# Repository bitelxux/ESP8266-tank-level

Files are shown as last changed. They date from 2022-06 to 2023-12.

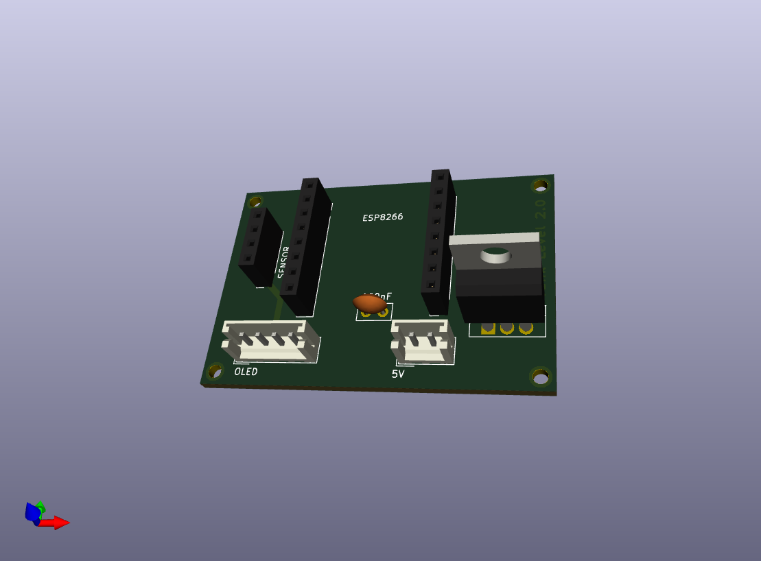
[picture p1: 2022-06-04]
kicad/water.tank/board.png

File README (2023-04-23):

2023/04/22
===================================================================================

Created branch DHT-11

2023/04/21
===================================================================================

Last kown working environment

Arduino IDE 2.1.0

Libaries:

Name                    Installed Available Location              Description                           
Adafruit_BusIO          1.14.1    -         LIBRARY_LOCATION_USER -                                     
Adafruit_GFX_Library    1.11.5    -         LIBRARY_LOCATION_USER -                                     
Adafruit_SSD1306        2.5.7     -         LIBRARY_LOCATION_USER -                                     
Adafruit_Unified_Sensor 1.1.9     -         LIBRARY_LOCATION_USER -                                     
ArduinoJson             5.13.5    6.21.2    LIBRARY_LOCATION_USER An efficient and elegant JSON library...
cnn                               -         LIBRARY_LOCATION_USER -                                     
DHT_sensor_library      1.4.4     -         LIBRARY_LOCATION_USER -                                     
ESP_DoubleResetDetector 1.3.2     -         LIBRARY_LOCATION_USER -                                     
NTPClient               3.2.1     -         LIBRARY_LOCATION_USER -                                     
WiFiManager             2.0.15-rc.1 -       LIBRARY_LOCATION_USER - 

Board: Generic ESP8266 board (3.0.2)

2022/05/13
===================================================================================

New version of https://github.com/bitelxux/levelsensor

Based in a ESP8266 reading from the sensor and uploading to a server
where very likely Grafana will show a nice chart.

It supports connection outages by storing values locally with a timestamp
and sending them once the connection is resumed.

This version will have a lot of improvements like pseudo-threads, 
smart use of EEPROM to store readings when connection to the server is not available,
WiFiManager to dynamically manage connections from any browser,
commands inyection from the server to force actions to happen in the
ESP like EEPROM reset or forget WiFis and much more !!

It's a Work in Progress !! Far from being finished !

Also the servers (tank level server and logs server) are not finished.

Link 'cnn' library to arduino's libraries directory
That 'cnn' library will be split from the main code at some point.
And it needs a proper name !

Keep syntonized if you want to see where this ends

First environment
============================================

 - Arduino IDE 1.8.15
 - Arduino AVR board 1.8.3
 - ESP8266 2.7.0

https://arduino.esp8266.com/stable/package_esp8266com_index.json
board: NodeMCU1.0 (ESP-12E Module)

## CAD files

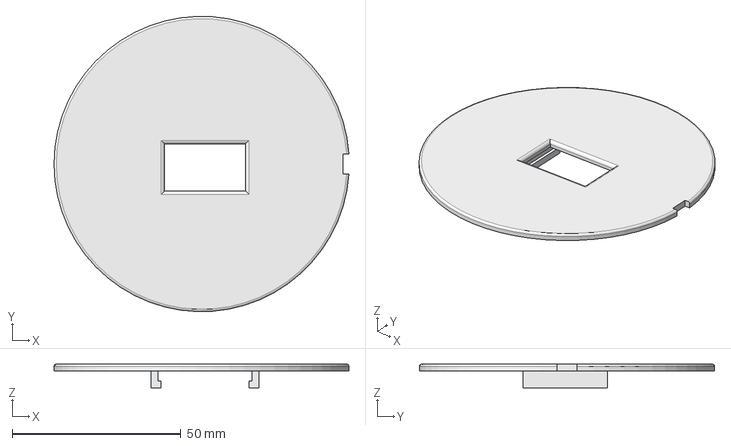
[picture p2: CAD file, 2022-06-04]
freecad/enclosure.FCStd
87.5 x 87.5 x 7.10 mm

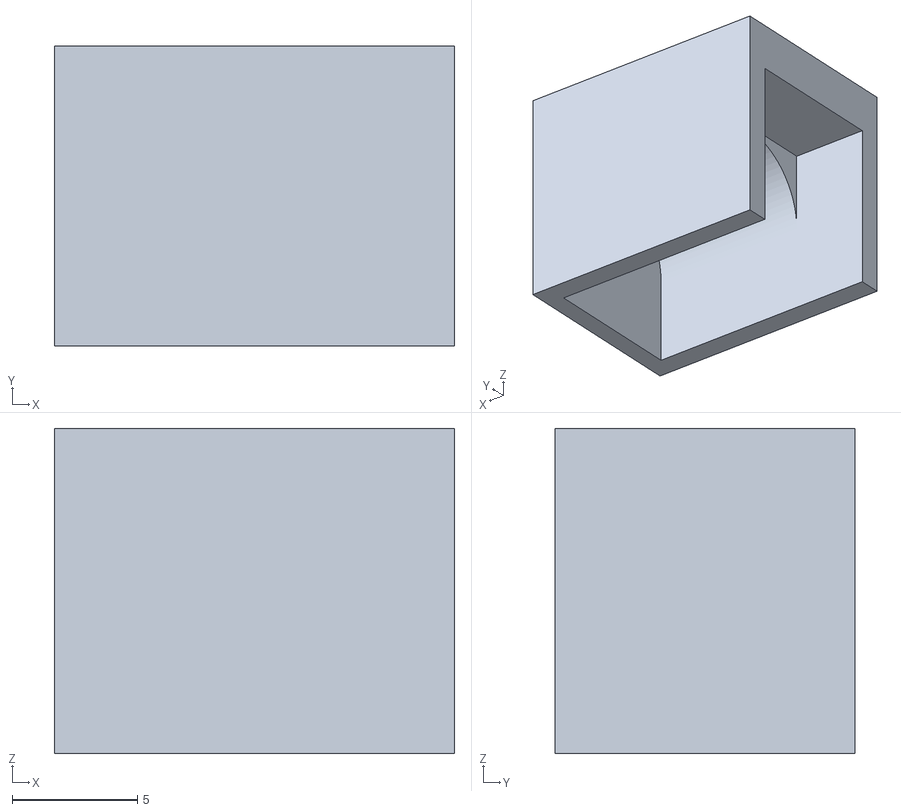
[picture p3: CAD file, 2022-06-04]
freecad/conector.stl
16.0 x 12.0 x 13.0

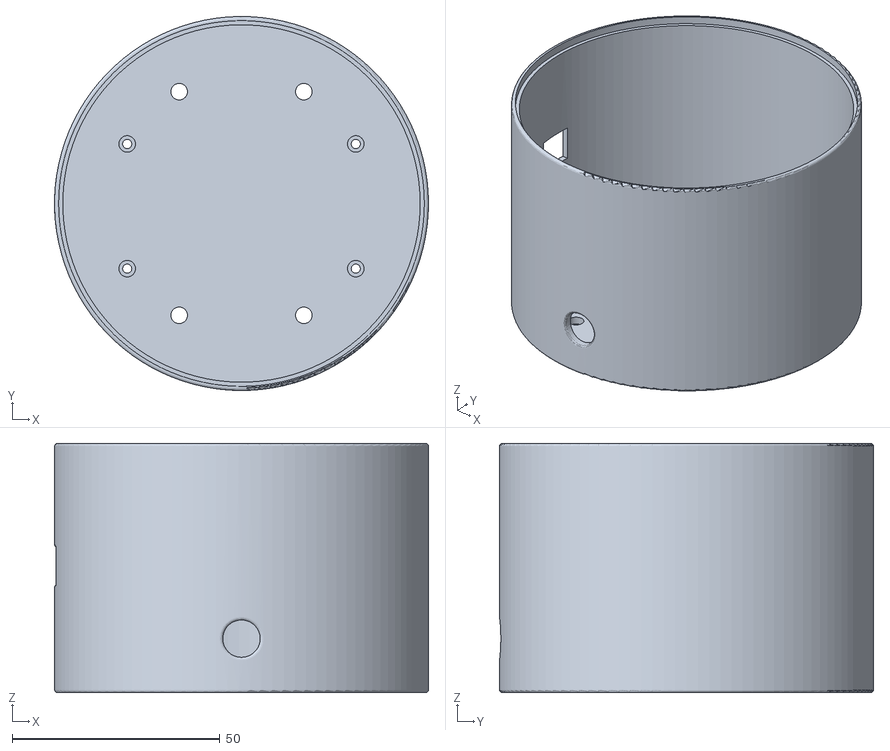
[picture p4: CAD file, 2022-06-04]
freecad/caja.stl
90.0 x 90.0 x 60.0

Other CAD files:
freecad/tapa.stl

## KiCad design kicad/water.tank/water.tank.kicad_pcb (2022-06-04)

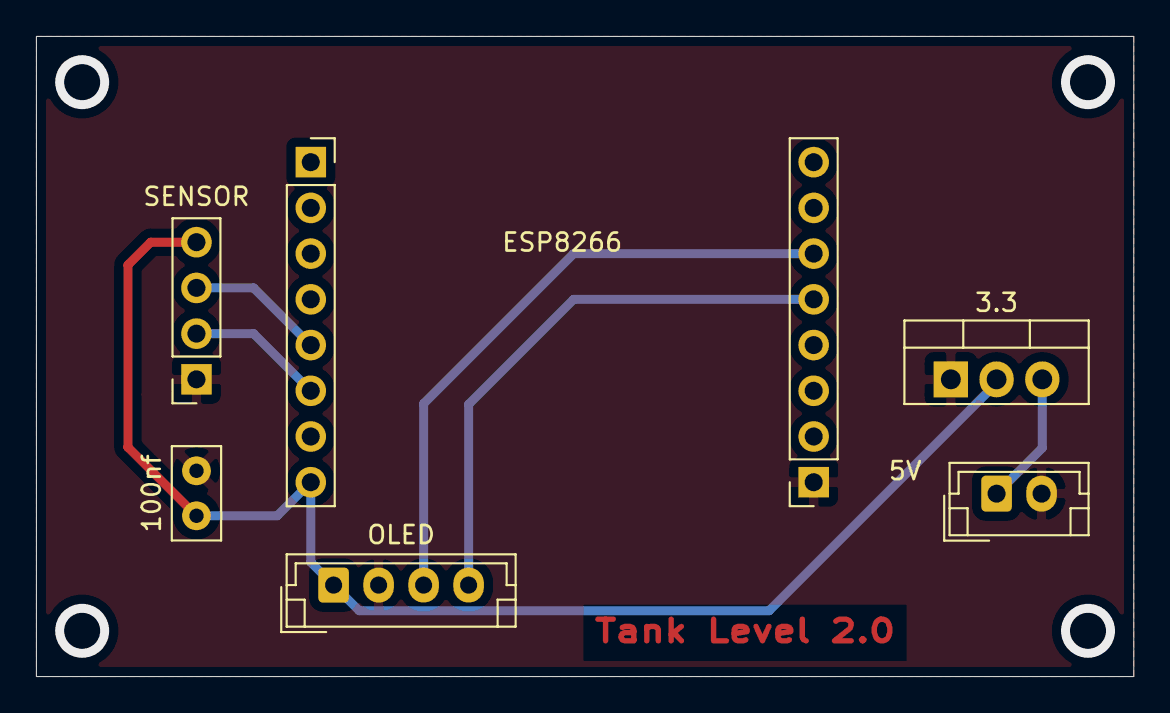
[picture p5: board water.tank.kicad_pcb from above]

Board: 2 copper layers, 61.0 x 35.6 mm, 7 parts (0 on the bottom side), 7 nets.

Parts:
3.3: LD33V; TO-220-3_Vertical
5V: source; JST_EH_B2B-EH-A_1x02_P2.50mm_Vertical
100nf: CAP; C_Disc_D5.0mm_W2.5mm_P2.50mm
ESP8266: ESP8266; PinSocket_1x08_P2.54mm_Vertical
J1: ESP8266; PinSocket_1x08_P2.54mm_Vertical
OLED: OLED1; JST_EH_B4B-EH-A_1x04_P2.50mm_Vertical
SENSOR: r; PinSocket_1x04_P2.54mm_Vertical

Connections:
5V: 3.3.3, 5V.1
GND: 3.3.1, 5V.2, 100nf.2, ESP8266.1, OLED.2, SENSOR.1
IO04: ESP8266.5, OLED.4
IO05: ESP8266.6, OLED.3
IO12: J1.6, SENSOR.2
IO14: J1.5, SENSOR.3
VCC: 3.3.2, 100nf.1, J1.8, OLED.1, SENSOR.4

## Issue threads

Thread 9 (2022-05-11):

make a first read after boot

bitelxux, 2022-05-11:
Or change the timers to be fired at t0
The problem as the read and display are not updated until the first read that now happens at t0+timer

bitelxux, 2022-05-13:
done

Closed 2022-05-13.

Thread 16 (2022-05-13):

test new JSN-SR20-Y1 double sensor

bitelxux, 2022-05-13:
configure it to continuosly send reading over serial. 47K resistor.

bitelxux, 2022-05-13:
I didn't have any smd 47K resistor. Soldered a regular one making the JSN-SR20-Y1 to look like if it has grown some weird organ

bitelxux, 2022-05-13:
done

Closed 2022-05-13.

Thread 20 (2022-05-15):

support jsn sensor mode 1 too

bitelxux, 2022-05-15:
Initial testing was done with sensor on mode 2, after soldering a 47K resistor, it continuosly sends the distance over serial.
But I have managed to ruin the solder area for the resistor and I can't solder it again so I need to support mode 1 now ( trigger + echo ) as I don't have another JSN board at the moment.

Closed 2022-05-15.

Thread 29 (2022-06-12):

Implement reset  button

bitelxux, 2022-06-12:
To be pressed for let's  say 10 seconds and then  reset WiFi configuration and EEPROM

bitelxux, 2022-06-12:
Implemented on GPIO14
If it's connected to ground for longer than 10 seconds, the wifi configuration will  be reseted and EEPTOM deleted.
Board will reboot too and Wifi will need to be re-configured

Closed 2022-06-12.

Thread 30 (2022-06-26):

Add REST server

bitelxux, 2022-06-26:
ref: https://www.mischianti.org/2020/05/16/how-to-create-a-rest-server-on-esp8266-and-esp32-startup-part-1/

For:

- reset EEPROM
- get stats
- force reading
- etc

Closed 2022-07-22.

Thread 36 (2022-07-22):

Use NTP + millis()

bitelxux, 2022-07-22:
Allow the recording of readings when there is no connection to the server if, at least, time was synced at some point

bitelxux, 2022-07-23:
Doesn't work. Reverting change.

Closed 2022-07-24.

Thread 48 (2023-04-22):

New arduino IDE (2.1.0) ATM

bitelxux, 2023-04-22:
```
Arduino IDE 2.1.0

Libaries:

Name                    Installed Available Location              Description                   
Adafruit_BusIO          1.14.1    -         LIBRARY_LOCATION_USER -                             
Adafruit_GFX_Library    1.11.5    -         LIBRARY_LOCATION_USER -                             
Adafruit_SSD1306        2.5.7     -         LIBRARY_LOCATION_USER -                             
Adafruit_Unified_Sensor 1.1.9     -         LIBRARY_LOCATION_USER -                             
ArduinoJson             5.13.5    6.21.2    LIBRARY_LOCATION_USER An efficient and elegant JSON library...
cnn                               -         LIBRARY_LOCATION_USER -                             
DHT_sensor_library      1.4.4     -         LIBRARY_LOCATION_USER -                             
ESP_DoubleResetDetector 1.3.2     -         LIBRARY_LOCATION_USER -                             
NTPClient               3.2.1     -         LIBRARY_LOCATION_USER -                             
WiFiManager             2.0.15-rc.1 -       LIBRARY_LOCATION_USER -

Board: Generic ESP8266 board (3.0.2)

```

bitelxux, 2023-04-22:
Program building and working.

Closed 2023-04-22.

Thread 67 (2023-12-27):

Prevent wifimanager to start WebPortal when configured ESSID is not available

bitelxux, 2023-12-27:
If the board starts and there is a configured SSID but it's not available, it will start the WebPortal to configure WIFI and hang there.

Prevent the WebPortal from starting IF a SSID is configured. Rather than that, wait for the SSID to become available.

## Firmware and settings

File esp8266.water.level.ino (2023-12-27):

//Libraries
#include <FS.h>
#include <ArduinoJson.h>     // 5.13.5 !!

#include <ESP8266WebServer.h>

#include <cnn.h>
#include "sensor_JSN-SR04T.h"

// This is for each variable to use it's real size when stored
// in the EEPROM
#pragma pack(push, 1)

#define BOARD_ID "tank.Z"
#define VERSION "20231227.272"

//EEPROM
#define EEPROM_SIZE 4096
#define RESERVED_BYTES 10
#define COUNTER_SLOTS 10

#define CURRENT_COUNTER_SLOT_ADDRESS 0   // 1 byte
#define MAX_WRITES 100000                // theorically 10000
#define WARNINGS_ADDRESS 1               // bitmap supporting 8 predefined warnings
#define BOOTS_ADDRESS 2                  // 2 bytes

#define WARNING_COUNTER_SLOTS_ROTATED  1 // counter slots were exhaested and ressetted to 1
#define WARNING_STORAGE_IS_FULL 2
#define WARNING_2 4
#define WARNING_3 8
#define WARNING_4 16
#define WARNING_5 32
#define WARNING_6 64
#define WARNING_7 128

#define FLUSH_BATCH_SIZE 50

#define REC_NEVER_USED 0
#define REC_IN_USE 1
#define REC_FLUSHED 2

// 10 bytes are reserver for general data
// we reserve space for 10 counters, 4 byte each
// for each counter, first two bytes is the number
// of write operations on the counter
// the second two bytes is the counter itself
// #define RECORDS_BASE_ADDRESS RESERVED_BYTES + 4 * COUNTER_SLOTS 
//\\ EEPROM

#define RSSI_MAX -50  // maximum strength of signal in dBm
#define RSSI_MIN -100 // minimum strength of signal in dBm

// WiFiManager parameteres
#define SERVER_LABEL "SERVER_IP"

// Reset Button
#define RESET_BUTTON 14
unsigned long rb_last_change = 0;
int rb_required_time = 3;
boolean time_to_reset = false;

App *app = NULL;
SR04T_sensor* sensor = NULL;

//flag for saving data
bool shouldSaveConfig = false;

//callback notifying us of the need to save config
void saveConfigCallback () {
  Serial.println("Should save config");
  shouldSaveConfig = true;
}

typedef struct
{
  byte flag;
  unsigned long timestamp;
  unsigned short value;
} Reading;

unsigned short int RECORDS_BASE_ADDRESS = RESERVED_BYTES + 4 * COUNTER_SLOTS;
unsigned short int MAX_RECORDS = (EEPROM_SIZE - RECORDS_BASE_ADDRESS)/sizeof(Reading) -1;
// TODO review that -1. It's not the best approach

int counter = 0; // number of registers in EEPROM
int lastReading = 0;
char buffer[200];

// prototipes
void flushStoredData();
void registerNewReading();

ESP8266WebServer restServer(80);

// This values  will depend on what the user configures
// on the  WifiManager on the first connection
char server[16];
char log_server[30];
char baseURL[30];

//OLED
#include <SPI.h>
#include <Wire.h>
#include <Adafruit_GFX.h>
#include <Adafruit_SSD1306.h>

boolean displayInitialized = false;

#define SCREEN_WIDTH 128 // OLED display width, in pixels
#define SCREEN_HEIGHT 64 // OLED display height, in pixels

// Declaration for an SSD1306 display connected to I2C (SDA, SCL pins)
#define OLED_RESET     -1 // Reset pin # (or -1 if sharing Arduino reset pin)

// SCL is GPI05
// SDA is GPI04
Adafruit_SSD1306 display(SCREEN_WIDTH, SCREEN_HEIGHT, &Wire, OLED_RESET);

static const unsigned char PROGMEM wifi_bmp[] = 
{
0x00, 0x00, 0x00, 0x00, 0x07, 0xe0, 0x1f, 0xf8, 0x70, 0x0e, 0xe0, 0x07, 0x07, 0xe0, 0x1e, 0x78,
0x18, 0x18, 0x03, 0xc0, 0x07, 0xe0, 0x00, 0x00, 0x01, 0x80, 0x01, 0x80, 0x00, 0x00, 0x00, 0x00
};

static const unsigned char PROGMEM nowifi_bmp[] = 
{
0x00, 0x01, 0x00, 0x3e, 0x01, 0xfe, 0x00, 0xfe, 0x00, 0xfe, 0x01, 0xfe, 0x03, 0x3c, 0x20, 0x3c,
0x30, 0x64, 0x38, 0x40, 0x7c, 0x00, 0x7e, 0x00, 0x7f, 0x00, 0x7f, 0x80, 0x7c, 0x00, 0x80, 0x00
};

static const unsigned char PROGMEM send_bmp[] = 
{
0x00, 0x00, 0x09, 0x00, 0x04, 0x00, 0x00, 0x80, 0x02, 0x40, 0x01, 0x20, 0x00, 0x80, 0x00, 0x90,
0x00, 0x90, 0x00, 0x80, 0x01, 0x20, 0x02, 0x40, 0x00, 0x80, 0x04, 0x00, 0x09, 0x00, 0x00, 0x00
};

static const unsigned char PROGMEM store_bmp[] = 
{
0x7f, 0xfc, 0xe0, 0x6e, 0xe0, 0x6f, 0xe0, 0x6f, 0xe0, 0x6f, 0xe0, 0x2f, 0xff, 0xff, 0xff, 0xff,
0xc0, 0x03, 0xc0, 0x03, 0xc0, 0x03, 0xc0, 0x03, 0xc0, 0x03, 0xc0, 0x03, 0xc0, 0x03, 0x7f, 0xfe
};

static const unsigned char PROGMEM disconnected_bmp[] = 
{
0x00, 0x01, 0x00, 0x3e, 0x01, 0xfe, 0x00, 0xfe, 0x00, 0xfe, 0x01, 0xfe, 0x03, 0x3c, 0x20, 0x3c,
0x30, 0x64, 0x38, 0x40, 0x7c, 0x00, 0x7e, 0x00, 0x7f, 0x00, 0x7f, 0x80, 0x7c, 0x00, 0x80, 0x00
};

static const unsigned char PROGMEM connected_bmp[] = 
{
0x00, 0x01, 0x00, 0x02, 0x00, 0x64, 0x00, 0xf8, 0x07, 0xf8, 0x0b, 0xfc, 0x0d, 0xfc, 0x1e, 0xf8,
0x1f, 0x78, 0x3f, 0xb0, 0x3f, 0xd0, 0x1f, 0xe0, 0x1f, 0x00, 0x26, 0x00, 0x40, 0x00, 0x80, 0x00
};

static const unsigned char PROGMEM warning_bmp[] = {
	0x00, 0x00, 0x00, 0x00, 0x00, 0x00, 0x01, 0x80, 0x01, 0x80, 0x02, 0x40, 0x06, 0x60, 0x06, 0x60, 
	0x0e, 0x70, 0x1f, 0xf8, 0x1e, 0x78, 0x3e, 0x7c, 0x00, 0x00, 0x00, 0x00, 0x00, 0x00, 0x00, 0x00
};

void clearSection(int x, int y, int x1, int y1){
  display.fillRect(x, y, x1, y1, 0);
  display.display();
}

void drawTank(){
  sensor->draw(&display, lastReading);
}

void drawStore(){
  display.drawBitmap(94, 0, store_bmp, 16, 16, 1);
  display.display();
}

void drawSend(){
  display.drawBitmap(94, 0, send_bmp, 16, 16, 1);
  display.display();
}

void updateDisplay(){

  if (!displayInitialized) {
    Serial.println("Display not initialized");
    return;
  }

  display.clearDisplay();

  drawTank();

  if (readWarnings()){
      display.drawBitmap(18, 0, warning_bmp, 16, 16, 1);
  }

  if (isServerAlive()){
      display.drawBitmap(0, 0, connected_bmp, 16, 16, 1);
  }
  else
  {
      display.drawBitmap(0, 0, disconnected_bmp, 16, 16, 1);
  }

  if (WiFi.status() == WL_CONNECTED){
      display.drawBitmap(112, 0, wifi_bmp, 16, 16, 1);
  }
  else
  {
      display.drawBitmap(112, 0, nowifi_bmp, 16, 16, 1);
  }

  display.setTextSize(1);             // Normal 1:1 pixel scale
  display.setTextColor(WHITE);        // Draw white text
  display.setCursor(0,18);            

  display.setCursor(40,5);            
  display.print(BOARD_ID);

  display.setCursor(0,18);
  display.print(sensor->READ_LABEL);
  display.setCursor(46,18);            
  display.print(lastReading);

  unsigned short int counter = readCounter();
  display.setCursor(0,26);            
  display.print("Local: ");
  display.setCursor(46,26);            
  display.print(counter);

  display.setCursor(0,48);            
  display.print(VERSION);

  display.setCursor(0,56);            
  display.print(app->IP);

  display.display();
}

void initOLED(){

  // SSD1306_SWITCHCAPVCC = generate display voltage from 3.3V internally
  if(display.begin(SSD1306_SWITCHCAPVCC, 0x3C)) { 
    Serial.println("SSD1306 found and intialized");
    displayInitialized = true;
  }
  else {
    Serial.println("SSD1306 allocation failed");
  }

  // Show initial display buffer contents on the screen --
  // the library initializes this with an Adafruit splash screen.
  display.display();
  delay(2000); // Pause for 2 seconds
}

bool isServerAlive(){
    sprintf(buffer, "%s/ping", baseURL);
    //Serial.println(buffer);
    return (app->send(buffer));
}

void registerNewReading(){
  int distance;
  int counter;
  char buffer[100];

  // some attempts to read a value from sensor
  for (int i=0; i<10; i++){
      distance = sensor->read();
      if (distance != -1){
        break;
      }
      delay(20);
  }

  if (distance <= 0){
    app->log("Error reading value from sensor");
    return;
  }

  sprintf(buffer, "LOG: read distance is %d", distance);
  app->log(buffer);

  int litres = sensor->calcLitres(distance);
  lastReading = litres;

  unsigned long now = app->getEpochSeconds();
  if (now){
    sprintf(buffer, "%s/add/%d:%d", baseURL, now, litres);

    // try to send to the server
    // if fails, store locally for further retrying
    if (app->send(buffer)){
      drawSend();
      sprintf(buffer, "Sent %d:%d", now, litres);
      app->log(buffer);
    }
    else{
      drawStore();
      counter = writeReading(now, litres);
    }
        
  }
  else{
      app->log("Warning: Not handling reading as time is not synced");
  }

}

void flushStoredData(){


  Reading reading;  
  unsigned short int counter = readCounter();
  unsigned short int cursor = 0;
  unsigned short int regAddress;
  short int value;
  bool errors = false;
  byte flag;
  unsigned short int recNum;
  unsigned short int sent = 0;
  int regSize = sizeof(reading);
  char buffer[100];
 
  // You have to start server.py at BASE_URL
  if (!isServerAlive()){
    sprintf(buffer, "[FLUSH_STORED_DATA] Server doesn't respond. I'll try later.");
    app->log(buffer);
    return;
  }

  if (WiFi.status() != WL_CONNECTED){
    app->log("[FLUSH_STORED_DATA] Skipping. I'm not connected to the WIFI :-/.");
    return;
  }

  if (counter == 0){
      app->log("[FLUSH_STORED_DATA] Nothing to send");
      return;
  }

  for (regAddress = RECORDS_BASE_ADDRESS; regAddress < EEPROM_SIZE; regAddress += regSize){

      if (counter == 0 || sent >= FLUSH_BATCH_SIZE){
         break;
      }
      
      EEPROM.get(regAddress, reading);

      // if value is REC_FLUSHED that register was already sent
      // 0 the position hasn't been used yet
      if (reading.flag == REC_FLUSHED){
        continue;
      }

      // flag 0 means that position or higher have never been used
      if (reading.flag == REC_NEVER_USED){
        return;
      }

      recNum = (regAddress - RECORDS_BASE_ADDRESS)/regSize;
      sprintf(buffer, "%s/add/%d:%d", baseURL, reading.timestamp, reading.value);

      if (!app->send(buffer)){
        sprintf(buffer, "[FLUSH_STORED_DATA] Error sending record [%d]", recNum);
        app->log(buffer);
        errors = true;
        if (!isServerAlive()){
          sprintf(buffer, "[FLUSH_STORED_DATA] Server doesn't respond. I'll try later.");
          app->log(buffer);
          break;
        }

      }
      else
      {
        drawSend();
        counter = decCounter();
        sent ++;
        
        sprintf(buffer, "[FLUSH_STORED_DATA] Success sending record [%d] (%d left)", recNum, readCounter());
        app->log(buffer);

        // We don't want to write the whole struct to save write cycles
        flag = REC_FLUSHED;
        EEPROM.write(regAddress, flag);
        EEPROM.commit();

        removeWarning(WARNING_STORAGE_IS_FULL);

        updateDisplay();
      }

  }

  if (!errors){
      sprintf(buffer, "[FLUSH_STORED_DATA] %d records sent", sent);
      // to correct a buggy counter out of sync error that sometimes happens
      if (sent == 0){
        writeCounter(0);
      }
  } else {
      sprintf(buffer, "[FLUSH_STORED_DATA] %d records sent [errors]", sent);    
  }
  
  app->log(buffer);

}

unsigned short int incCounter(){
  counter = readCounter() + 1;
  writeCounter(counter);
  return counter;
}

unsigned short int decCounter(){
  counter = readCounter() - 1;
  writeCounter(counter);
  return counter;
}

byte readWarnings(){
  byte warnings;   
  warnings = EEPROM.read(WARNINGS_ADDRESS);
  return warnings;
}

void removeWarnings(){
  EEPROM.write(WARNINGS_ADDRESS, 0);
  EEPROM.commit();
}

byte removeWarning(byte warning){
  byte warnings = readWarnings();
  if (!(warnings && warning)){
    // warning was not set. nothing to remove
    return warnings;
  }
  warnings ^= warning;
  EEPROM.write(WARNINGS_ADDRESS, warnings);
  EEPROM.commit();
  return warnings;
}

byte addWarning(byte warning){
  byte warnings = readWarnings();
  warnings |= warning;
  EEPROM.write(WARNINGS_ADDRESS, warnings);
  EEPROM.commit();
  return warnings;
}

unsigned short int readCounter(){
  byte counterAddress;   
  unsigned short int counter;
  EEPROM.get(CURRENT_COUNTER_SLOT_ADDRESS, counterAddress);
  EEPROM.get(counterAddress + 2, counter); // skip counter writes: 2 bytes
  return counter;
}

int getCounterSlot(){
  byte counterAddress;
  int counterSlot;

  EEPROM.get(CURRENT_COUNTER_SLOT_ADDRESS, counterAddress);
  counterSlot = (counterAddress-RESERVED_BYTES-1)/4 + 1;
  return counterSlot;
}

void writeCounter(unsigned short int counter){
  byte counterAddress;
  int counterSlot;
  unsigned short int counterWrites;

  EEPROM.get(CURRENT_COUNTER_SLOT_ADDRESS, counterAddress);
  EEPROM.get(counterAddress, counterWrites);

  counterSlot = getCounterSlot();

  if (counterWrites >= MAX_WRITES){
    // We are about to reach the 10K writes limit ...
    // moving to the next slot

    //sprintf(buffer, "Counter slot %d reaching the limit of %d writings", counterSlot, MAX_WRITES);
    //app->log(buffer);

    if (counterSlot <  COUNTER_SLOTS){
        counterSlot ++;
        counterAddress += 4; // each counter is 2 byte for n of writes + 2 bytes for the counter
        sprintf(buffer, "Counter slot moved to slot %d", counterSlot);
        app->log(buffer);
    }
    else{
        sprintf(buffer, "WARNING. Counter slots exhausted. Resetting to slot 1. Writes might start to fail soon");
        addWarning(WARNING_COUNTER_SLOTS_ROTATED);
        app->log(buffer);
        counterSlot = 1;
        counterAddress = 1;
    }

    counterWrites = 0;

    EEPROM.write(CURRENT_COUNTER_SLOT_ADDRESS, counterAddress);
  }

  EEPROM.put(counterAddress, counterWrites+1);
  EEPROM.put(counterAddress + 2, counter);
  
  //sprintf(buffer, "counter slot: %d, numwrites: %d", counterSlot, counterWrites+1);
  //app->log(buffer);

  if (!EEPROM.commit()) {
    app->log("Commit failed writing counter changes");
  }
}

int writeReading(unsigned long in_timestamp, short int in_value){
  
  int address;
  int regAddress;
  unsigned short int counter = readCounter();
 
  //sprintf(buffer, "writeReading %d %d", counter, MAX_RECORDS);
  //app->log(buffer);

  if (counter >= MAX_RECORDS){
    addWarning(WARNING_STORAGE_IS_FULL);
    app->log("WARNING. Local storage is full");
    return -1;
  }

  Reading newReading;
  Reading record;
  Reading currentReading;
  
  newReading.timestamp = in_timestamp;
  newReading.value = in_value;
  newReading.flag = REC_IN_USE;

  int regSize = sizeof(newReading);
  byte flag;

  for (address=RECORDS_BASE_ADDRESS; address < EEPROM_SIZE - regSize; address += regSize){
      EEPROM.get(address, flag);
      // flag is a used position
      if (flag != REC_IN_USE){
        EEPROM.put(address, newReading);
        EEPROM.commit();
        counter = incCounter();        
        sprintf(buffer, "Locally stored [%d of %d] %d:%d", counter, MAX_RECORDS, in_timestamp, in_value);
        app->log(buffer);
        break;
      }      
  }  

  return counter;
}

void dumpEEPROM(){

  unsigned short _byte;
  int offset = 0;
  int n = -1;
  boolean usingDefault = true;

  int freeRAM = ESP.getFreeHeap();

  sprintf(buffer, "free RAM = %d", freeRAM);
  app->log(buffer);
  
  if ( restServer.hasArg("n") ) {
    n = restServer.arg("n").toInt();
    usingDefault = false;
  }
  else {
    n = 10;
  }

  if ( n*12 > freeRAM) {
     restServer.send(200, "text/plain", "Not enough free RAM. Try to request less positions\n");
     return;
  }

  char buffer[n*12];

  if ( usingDefault ){
    sprintf(buffer, "'n' hasn't been specified. Defaulting to 10\n\n");
    offset=strlen(buffer);
    n = 10;
  }

  for (int i = 0; i < n; i++) {
    _byte = EEPROM.read(i);
    offset += sprintf(buffer + offset, "0x%04X: %d\n",i ,_byte);
  }

  restServer.send(200, "text/plain", buffer);
}

void resetEEPROM(){
  int t0 = millis();
  for (int i=0; i < EEPROM_SIZE; i++){
    EEPROM.write(i, 0);
  }

  EEPROM.write(CURRENT_COUNTER_SLOT_ADDRESS, RESERVED_BYTES);

  EEPROM.commit();
  int t2=millis();

  sprintf(buffer, "EEPROM deleted in %d milliseconds", t2 - t0);
  app->log(buffer);

  restServer.send(200, "text/plain", buffer);
}

void resetWIFI(){

  sprintf(buffer, "WIFI networks will be reset and board rebooted NOW");
  app->log(buffer);
  restServer.send(200, "text/plain", buffer);
  _resetWifi();
}

void readConfigFile(){
  Serial.println("mounting FS...");
  strcpy(server, "");

  if (SPIFFS.begin()) {
    Serial.println("mounted file system");
    if (SPIFFS.exists("/config.json")) {
      //file exists, reading and loading
      Serial.println("reading config file");
      File configFile = SPIFFS.open("/config.json", "r");
      if (configFile) {
        Serial.println("opened config file");
        size_t size = configFile.size();
        // Allocate a buffer to store contents of the file.
        std::unique_ptr<char[]> buf(new char[size]);

        configFile.readBytes(buf.get(), size);
        DynamicJsonBuffer jsonBuffer;
        JsonObject& json = jsonBuffer.parseObject(buf.get());
        json.printTo(Serial);
        if (json.success()) {
          Serial.println("\nparsed json");
          strcpy(server, json["server"]);
        } else {
          Serial.println("failed to load json config");
        }
      }
    }
  } else {
    Serial.println("failed to mount FS");
  }
}

ICACHE_RAM_ATTR void resetButtonPushed() {

    char buffer[20];
    static int t0 = millis();
    static bool armed = false;
    
    if (millis() - t0 < 200){
       t0 = millis();
       return;
    }

    if (!armed && digitalRead(RESET_BUTTON) == 0){ // pressed
       t0 = millis();
       armed = true;
    }

    if (armed && millis() - t0 > 10000){
       armed = false;
       time_to_reset = true;
       return;
    }
    
    if (digitalRead(RESET_BUTTON) == 1){ //released too soon
       Serial.println("RESET not performed");      
       armed = false;
    }

}

void checkConnection()  {
    if (WiFi.status() != WL_CONNECTED) {
      Serial.println("Reconnecting to WiFi...");
      WiFi.reconnect();
      
      int t = millis();
      
      while (millis() - t < 60000 && WiFi.status() != WL_CONNECTED){
        delay(2000);
        Serial.println("Reconnecting to WiFi...");
      }

      if (WiFi.status() == WL_CONNECTED){
        Serial.println("WiFi reconnected!");
      }
      else {
        Serial.println("Failed to reconnect to WiFi");
      }

    }
}

void isTimeToReset(){
  if (time_to_reset){
    app->log("RESET button has been pressed for more than 10 seconds. Resetting WIFI and  EEPROM");
    resetEEPROM();
    _resetWifi();
  }
}

char* millis_to_human(unsigned long millis)
{
    char* buffer = new char[100];

    int seconds = millis/1000;

    int days = int(seconds/86400);
    seconds = seconds % 86400;
    int hours = int(seconds/3600);
    seconds = seconds % 3600;
    int minutes = int(seconds/60);
    seconds = seconds % 60;

    sprintf(buffer, "%d days, %d hours, %d minutes, %d seconds", days, hours, minutes, seconds);
    return buffer;
}

// Serving Hello world
void getHelloWord() {
    restServer.send(200, "text/json", "{\"name\": \"Hello world\"}");
}

void boardID() {
    sprintf(buffer, "%s\n", BOARD_ID);
    restServer.send(200, "text/plain", buffer);
}

void scan_networks() {

  char *buffer = new char[1024];
  int n = WiFi.scanNetworks();
  char *connected = NULL;

  if (n == 0) {
    Serial.println("no networks found");
  } else {
    sprintf(buffer, "networks found:\n");
    for (int i = 0; i < n; ++i) {
      // Print SSID and RSSI for each network found

      if (WiFi.SSID(i) == WiFi.SSID()){
        connected = "*";
      } else {
        connected = " ";
      }
    
      sprintf(buffer + strlen(buffer), "%d [%s] %-32s dBM %d (%d%%)\n", 
                                       i+1,
                                       connected, 
                                       WiFi.SSID(i).c_str(), 
                                       WiFi.RSSI(i), 
                                       dBmtoPercentage(WiFi.RSSI(i)));
    }
  }
  restServer.send(200, "text/plain", buffer);
}

void get_readings() {
    sprintf(buffer, "%d\n", readCounter());
    restServer.send(200, "text/plain", buffer);
}

void wifi_signal() {
    sprintf(buffer, "%s [%d]\n", WiFi.SSID(), WiFi.RSSI());
    restServer.send(200, "text/plain", buffer);
}


void version() {
    sprintf(buffer, "%s\n", VERSION);
    restServer.send(200, "text/plain", buffer);
}

void uptime() {
    sprintf(buffer, "%s\n", millis_to_human(millis()));
    restServer.send(200, "text/plain", buffer);
}

void boots() {
    sprintf(buffer, "%d\n", readBoots());
    restServer.send(200, "text/plain", buffer);
}

void reboot() {
    app->log("Board is going to reboot");
    restServer.send(200, "text/plain", "OK\n");
    delay(2000);
    ESP.restart();
}

void  restReadWarnings(){
    byte warnings = readWarnings();
    sprintf(buffer, "%d\n", warnings);
    restServer.send(200, "text/plain", buffer);
}

void clearWarnings(){
    removeWarnings();
    restServer.send(200, "text/plain", "OK\n");
}

int dBmtoPercentage(int dBm)
{
  int quality;
    if(dBm <= RSSI_MIN)
    {
        quality = 0;
    }
    else if(dBm >= RSSI_MAX)
    {  
        quality = 100;
    }
    else
    {
        quality = 2 * (dBm + 100);
   }

   return quality;
}
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
void loop() {
  app->attendTimers();
  restServer.handleClient();
}

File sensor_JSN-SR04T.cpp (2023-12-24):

#include <Arduino.h>
#include "sensor_JSN-SR04T.h"

// all distances in meters
float TANK_RADIUS = 0.6;
float TANK_EMPTY_DISTANCE = 1.170;
float TANK_FULL_DISTANCE= 0.21;
float REMAINING_WATER_HEIGHT= 0.19;

// pre-calculated
float piR2=3.141516*TANK_RADIUS*TANK_RADIUS;
float MAX_VOLUME = 1000 * piR2 * (TANK_EMPTY_DISTANCE + REMAINING_WATER_HEIGHT);

// circular buffer
int sum = 0;
int elementCount = 0;
const int windowSize = 5;
int circularBuffer[windowSize];
int* circularBufferAccessor = circularBuffer;

unsigned char dataBuffer[4] = {0};
unsigned char CS;
int distance =  0;
int previous_distance = 0;

void appendToBuffer(short int value)
{
  *circularBufferAccessor = value;
  circularBufferAccessor++;
  if (circularBufferAccessor >= circularBuffer + windowSize) 
    circularBufferAccessor = circularBuffer;
}

int mobileAverage(int value)
{
  // try not to do movile average
  // it's done in grafana

  return value;

  sum -= *circularBufferAccessor;
  sum += value;
  appendToBuffer(value);
  if (elementCount < windowSize)
    ++elementCount;
  return (int) sum / elementCount;
}


SR04T_sensor::SR04T_sensor(App* app){
    this->app = app;
    this->sensor = new SoftwareSerial(RX, TX);
}

void SR04T_sensor::init(){
    // mode 2
    this->sensor->begin(9600);
    /*
    // mode 1
    pinMode(TRIGGER_PIN, OUTPUT); // Initializing Trigger Output and Echo Input
    pinMode(ECHO_PIN, INPUT);
    digitalWrite(TRIGGER_PIN, LOW); // Reset the trigger pin and wait a half a second
    delayMicroseconds(500);    
    */
}

int SR04T_sensor::read(){
    // use readSensor_mode1 or readSensor_mode2
    // depending on the model/sensor setup
    // Mode1: use trigger
    // Mode2: serial comm
    return this->readSensor_mode2();
}

int SR04T_sensor::calcLitres(short int distance){

    float fd = distance/1000.0; // meters
    float h = max((float)0.0, TANK_EMPTY_DISTANCE - fd);
    float v = piR2 * h * 1000;

    // There is some remaining water under the floating switch
    // that is not usable because the pumb is off at this level.
    // Yet, it is water in the tank
    v += piR2 * REMAINING_WATER_HEIGHT * 1000;

    return (int) v;
}


// Trigger + Echo mode
int SR04T_sensor::readSensor_mode1(){
    long t = 0; // Measure: Put up Trigger...
    digitalWrite(TRIGGER_PIN, HIGH); // Wait for 11 µs ...
    delayMicroseconds(11); // Put the trigger down ...
    digitalWrite(TRIGGER_PIN, LOW); // Wait for the echo ...
    t = pulseIn(ECHO_PIN, HIGH);

    int mm = t/(29.2*2)*10;

    //sprintf(buffer, "duration was %d. mm was %d", t, mm);
    //app->log(buffer);

    // wrong reading
    if (t == 0){
        return -1;
    }

    return(mobileAverage(mm));
}

// read from serial. Requires a 47K resistor soldered on the board.
int SR04T_sensor::readSensor_mode2(){

   char buffer[100];
   short int distance = 0;

   // Flush old readings from sensor
   while (this->sensor->available()){
     delay(5);
     this->sensor->read();
   }

   delay(20);

   if (this->sensor->available() > 0){
       delay(4);
    
       if (this->sensor->read() == 0xFF){
          dataBuffer[0] = 0xFF;
          for (int i=1; i<4; i++){
            dataBuffer[i] = this->sensor->read();
          }
       }
    
       //sprintf(buffer, "lectura: %02X,%02X,%02X,%02X", dataBuffer[0], dataBuffer[1], dataBuffer[2], dataBuffer[3]);
       //app->log(buffer);
    
       CS = dataBuffer[0] + dataBuffer[1] + dataBuffer[2];
    
       if (dataBuffer[3] == CS){
         distance = (dataBuffer[1] << 8) + dataBuffer[2];
         //sprintf(buffer, "lectura: %d", distance);
         //app->log(buffer);
         return mobileAverage(distance);
       }
       else{
         sprintf(buffer, "CS Error: %02X,%02X,%02X,%02X", dataBuffer[0], dataBuffer[1], dataBuffer[2], dataBuffer[3]);
         this->app->log(buffer);
         return -1;
       }
   }
   return -1;
}

void SR04T_sensor::draw(Adafruit_SSD1306* display, int value){
  int outerX = 90;
  int outerY = 18;
  int outerWidth = 37;
  int outerHeight = 46;
  display->drawRoundRect(outerX, outerY, outerWidth, outerHeight, 4, 1);

  int innerWidth = outerWidth - 4;
  int innerHeight = (value * outerHeight)/MAX_VOLUME;
  int innerX = outerX + 2;
  int innerY = outerY + 2 + outerHeight - innerHeight - 4;
  display->fillRoundRect(innerX, innerY, innerWidth, innerHeight, 4, 1);

  // flat surface
  display->fillRect(innerX, innerY, innerWidth, 4, 1);
}

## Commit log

2022-04-24 timer to class method working
2022-04-24 about to support App and user timers
2022-04-24 App and user timers working
2022-04-24 enabled rest of timers
2022-04-24 blink led moved to app
2022-04-24 replace pointer for object
    [esp8266.water.level.ino]
2022-04-27 simplify timers
2022-04-27 configure LEDs
2022-05-05 free LEDs pins
2022-05-08 counter slots management
2022-05-10 workaround to fix out of sync counter
    [esp8266.water.level.ino]
2022-05-11 [8] fixes around memory management
    [esp8266.water.level.ino]
2022-05-13 dirty fix to reach MAX_RECORDS
    [esp8266.water.level.ino]
2022-05-15 add more resources
    [enclosure.FCStd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]
2022-06-04 a few unrelated things
    [caja.stl, conector.stl, enclosure.FCStd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]
2022-06-05 [23] README for MySQL on ARM
2022-06-09 [25] version and board id
2022-06-12 [28][29] fix and show version
    [esp8266.water.level.ino]
2022-06-12 [29] reset button
2022-07-23 36] reverting change as it doesn't work
    [esp8266.water.level.ino]
2022-07-24 [36] NTP + millis is working now
2022-07-24 [36] NTP + millis is working now (typo)
2022-07-25 [3] fix boots address and add rest to get and remove warnings
    [esp8266.water.level.ino]
2022-08-13 [38] uptime REST endpoing (fix text)
    [esp8266.water.level.ino]
2022-11-01 [32] reset wifi REST API
    [esp8266.water.level.ino]
2022-11-27 pin grafana and user
2022-12-11 [42] reset wifi REST
    [esp8266.water.level.ino]
2022-12-11 [43] wait for router after power outage
2023-04-22 [48] new arduino IDE 2.1.0
2023-04-22 [49] REST endpoint to reset boots
    [esp8266.water.level.ino]
2023-04-30 [53] fix wifi reconnection
    [esp8266.water.level.ino]
2023-04-30 [54] add basic logging capacity to the server
2023-05-02 [58] split tank level sensor logic from main code
2023-05-02 [61] initialize distance sensor
2023-12-27 [67] Prevent WebPortal to start if SSID is configured
    [esp8266.water.level.ino]
2024-04-20 change influxdb to a generic 'devices' table
